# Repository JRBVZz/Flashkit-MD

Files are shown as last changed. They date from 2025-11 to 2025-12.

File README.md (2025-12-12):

#### Flashkit MD дампер картриджей для Sega Mega Drive

Данный дампер/программатор позволяет читать и перезаписывать [совместимые картриджи](https://github.com/JRBVZz/SEGA-MD-Cart). Главное отличие данного форка - это возможность использовать адаптеры для флэш памяти в корпусах TSOP48, таким образом можно выпаять память из несовместимого картриджа и перезаписать её. При этом swap byte для записываемого ROM делать не нужно!

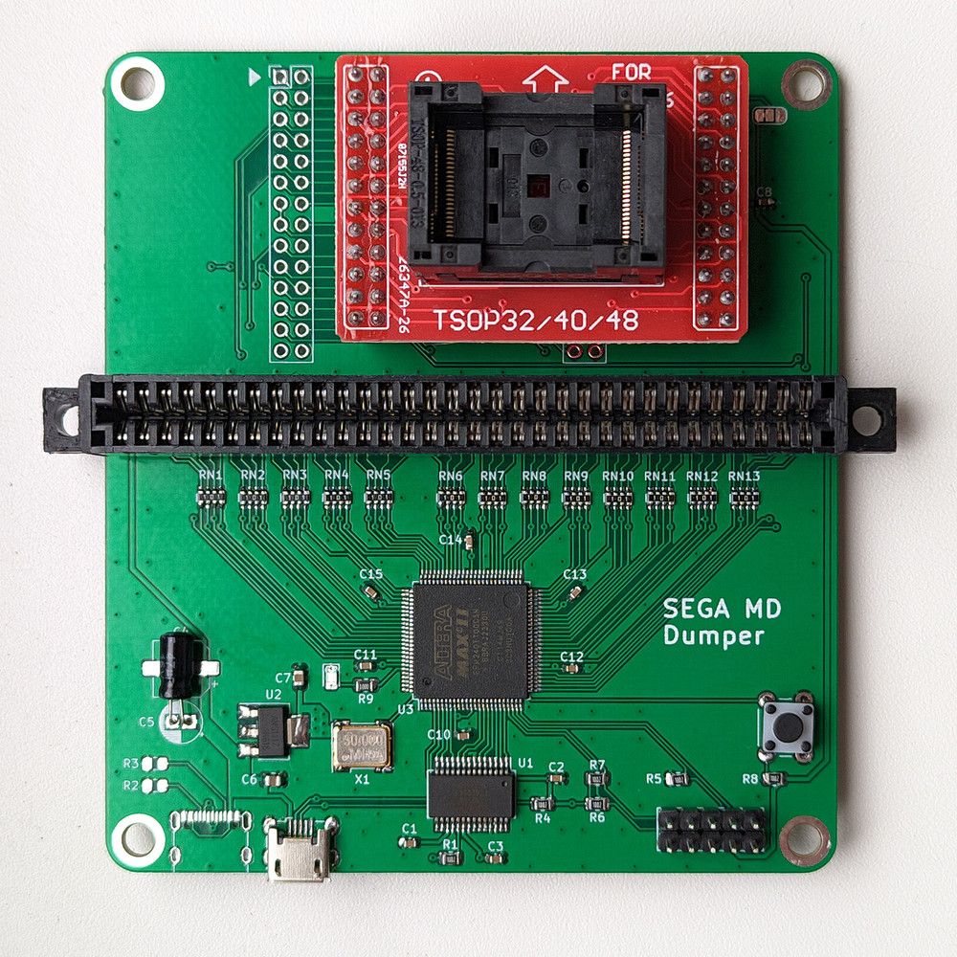
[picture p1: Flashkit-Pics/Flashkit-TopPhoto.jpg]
Front


**Схема**  
[Schematic PDF](Flashkit-Pics/Flashkit-Schematic.pdf)

**Интерактивный BOM**  
[BoM](BOM/Flashkit-iBOM.html) (для корректного просмотра нужно скачать raw файл)

**Прошивка**  
В папке Flashkit-Firmware находятся исходники проекта для Quartus, логика не менялась, был изменен порядок выводов EPM240.

**Софт**  
В папке Flashkit-Soft находится программа для работы с Flashkit и её исходники. Продвинутую версию программы от MiGeRA можно [скачать здесь](https://github.com/MiGeRA/FlashKit-MD-Plus).

**Использование адаптеров**  
В продаже можно найти дешевые TSOP56 адаптеры под пайку (A) и TSOP48 адаптер для TL866 (B), нужна только верхняя часть с кроваткой для микросхемы. Учтите, что у дампера для разных адаптеров свое посадочное место. Для того, чтобы программа увидела адаптер с установленной памятью, необходимо соединить перемычку "FLASH" на плате дампера.

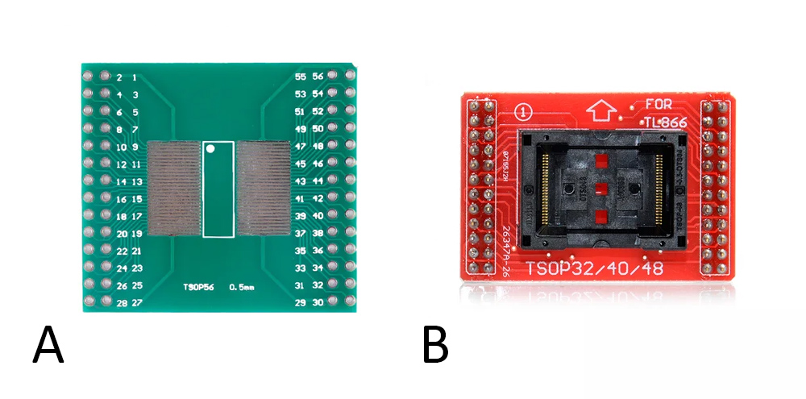
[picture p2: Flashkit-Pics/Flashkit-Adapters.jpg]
Adapters


При запайке чипа памяти в адаптер TSOP56, выводы микросхемы должны располагаться посередине посадочной площадки, т.е. сверху и снизу должно быть свободно по 2 контактные площадки.

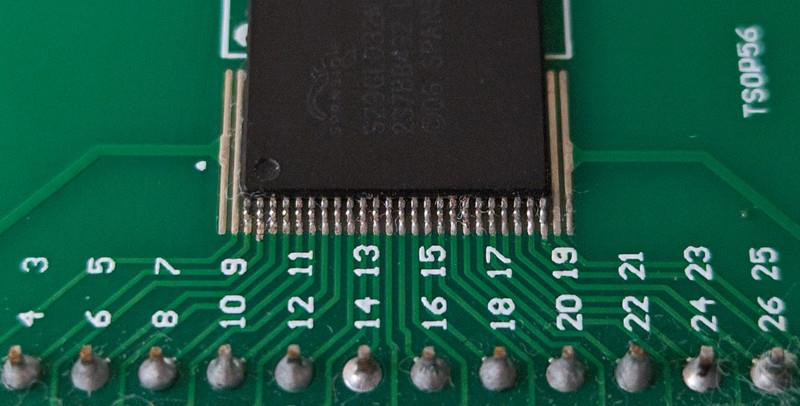
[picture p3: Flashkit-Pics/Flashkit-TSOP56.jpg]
TSOP56

  
Спасибо [**Krikzz**](https://github.com/krikzz) за этот отличный дампер.  
Проект создан в [**KiCad 9**](https://www.kicad.org/).  
PS Герберы не выкладываю специально - это мой небольшой вклад в популяризацию KiCad :smile:

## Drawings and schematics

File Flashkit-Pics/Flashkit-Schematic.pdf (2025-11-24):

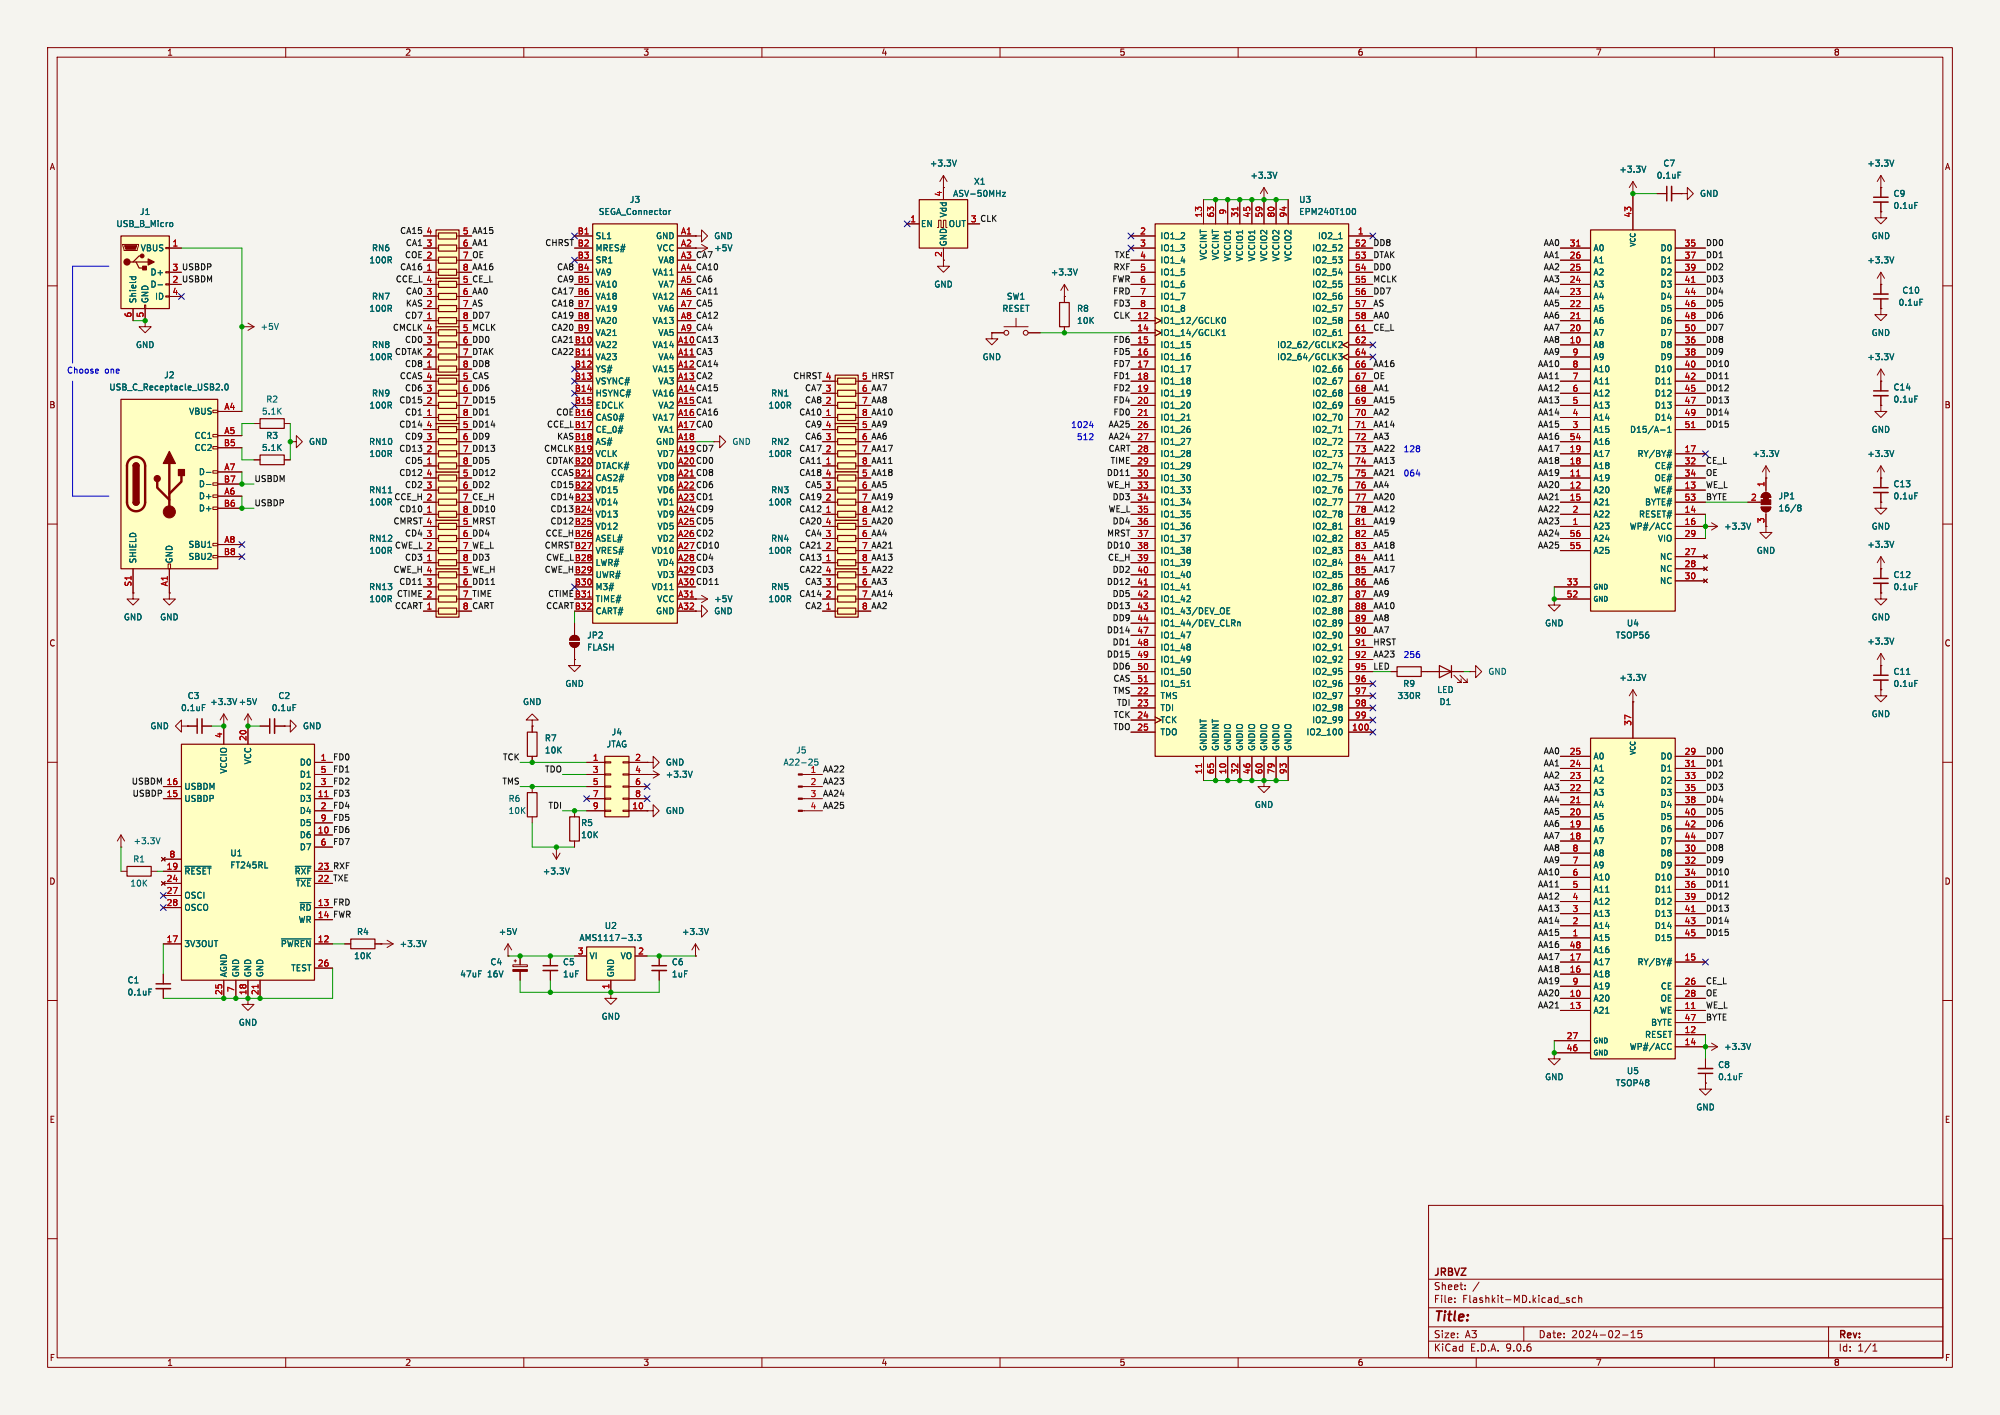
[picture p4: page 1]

J3 SEGA_Connector SL1 B1 MRES# B2 SR1 B3 VA9 B4 VA10 B5 VA18 B6 VA19 B7 VA20 B8 VA21 B9 VA22 B10 VA23 B11 YS# B12 VSYNC# B13 HSYNC# B14 EDCLK B15 CAS0# B16 CE_0# B17 AS# B18 VCLK B19 DTACK# B20 CAS2# B21 VD15 B22 VD14 B23 VD13 B24 VD12 B25 ASEL# B26 VRES# B27
SL1 B1 MRES# B2 SR1 B3 VA9 B4 VA10 B5 VA18 B6 VA19 B7 VA20 B8 VA21 B9 VA22 B10 VA23 B11 YS# B12 VSYNC# B13 HSYNC# B14 EDCLK B15 CAS0# B16 CE_0# B17 AS# B18 VCLK B19 DTACK# B20 CAS2# B21 VD15 B22 VD14 B23 VD13 B24 VD12 B25 ASEL# B26 VRES# B27

9 GNDIO 10 VCCIO1 31 GNDIO 32 VCCIO1 45 GNDIO 46 VCCIO2 59 GNDIO 60 VCCIO2 80 GNDIO 79 VCCIO2 94 GNDIO 93

7 VCC 20 GND 18 GND 21 D0 1 D1 5 D2 3 D3 11 D4 2 D5 9 D6 10 D7 6 ~{RXF}23 ~{TXE}22 ~{RD}13 WR 14 ~{PWREN}12 TEST 26 C1

7 VCC 20 GND 18 GND 21 D0 1 D1 5 D2 3 D3 11 D4 2 D5 9 D6 10 D7 6 ~{RXF}23 ~{TXE}22 ~{RD}13 WR 14 ~{PWREN}12 TEST 26 U1 FT245RL +3.3V GND

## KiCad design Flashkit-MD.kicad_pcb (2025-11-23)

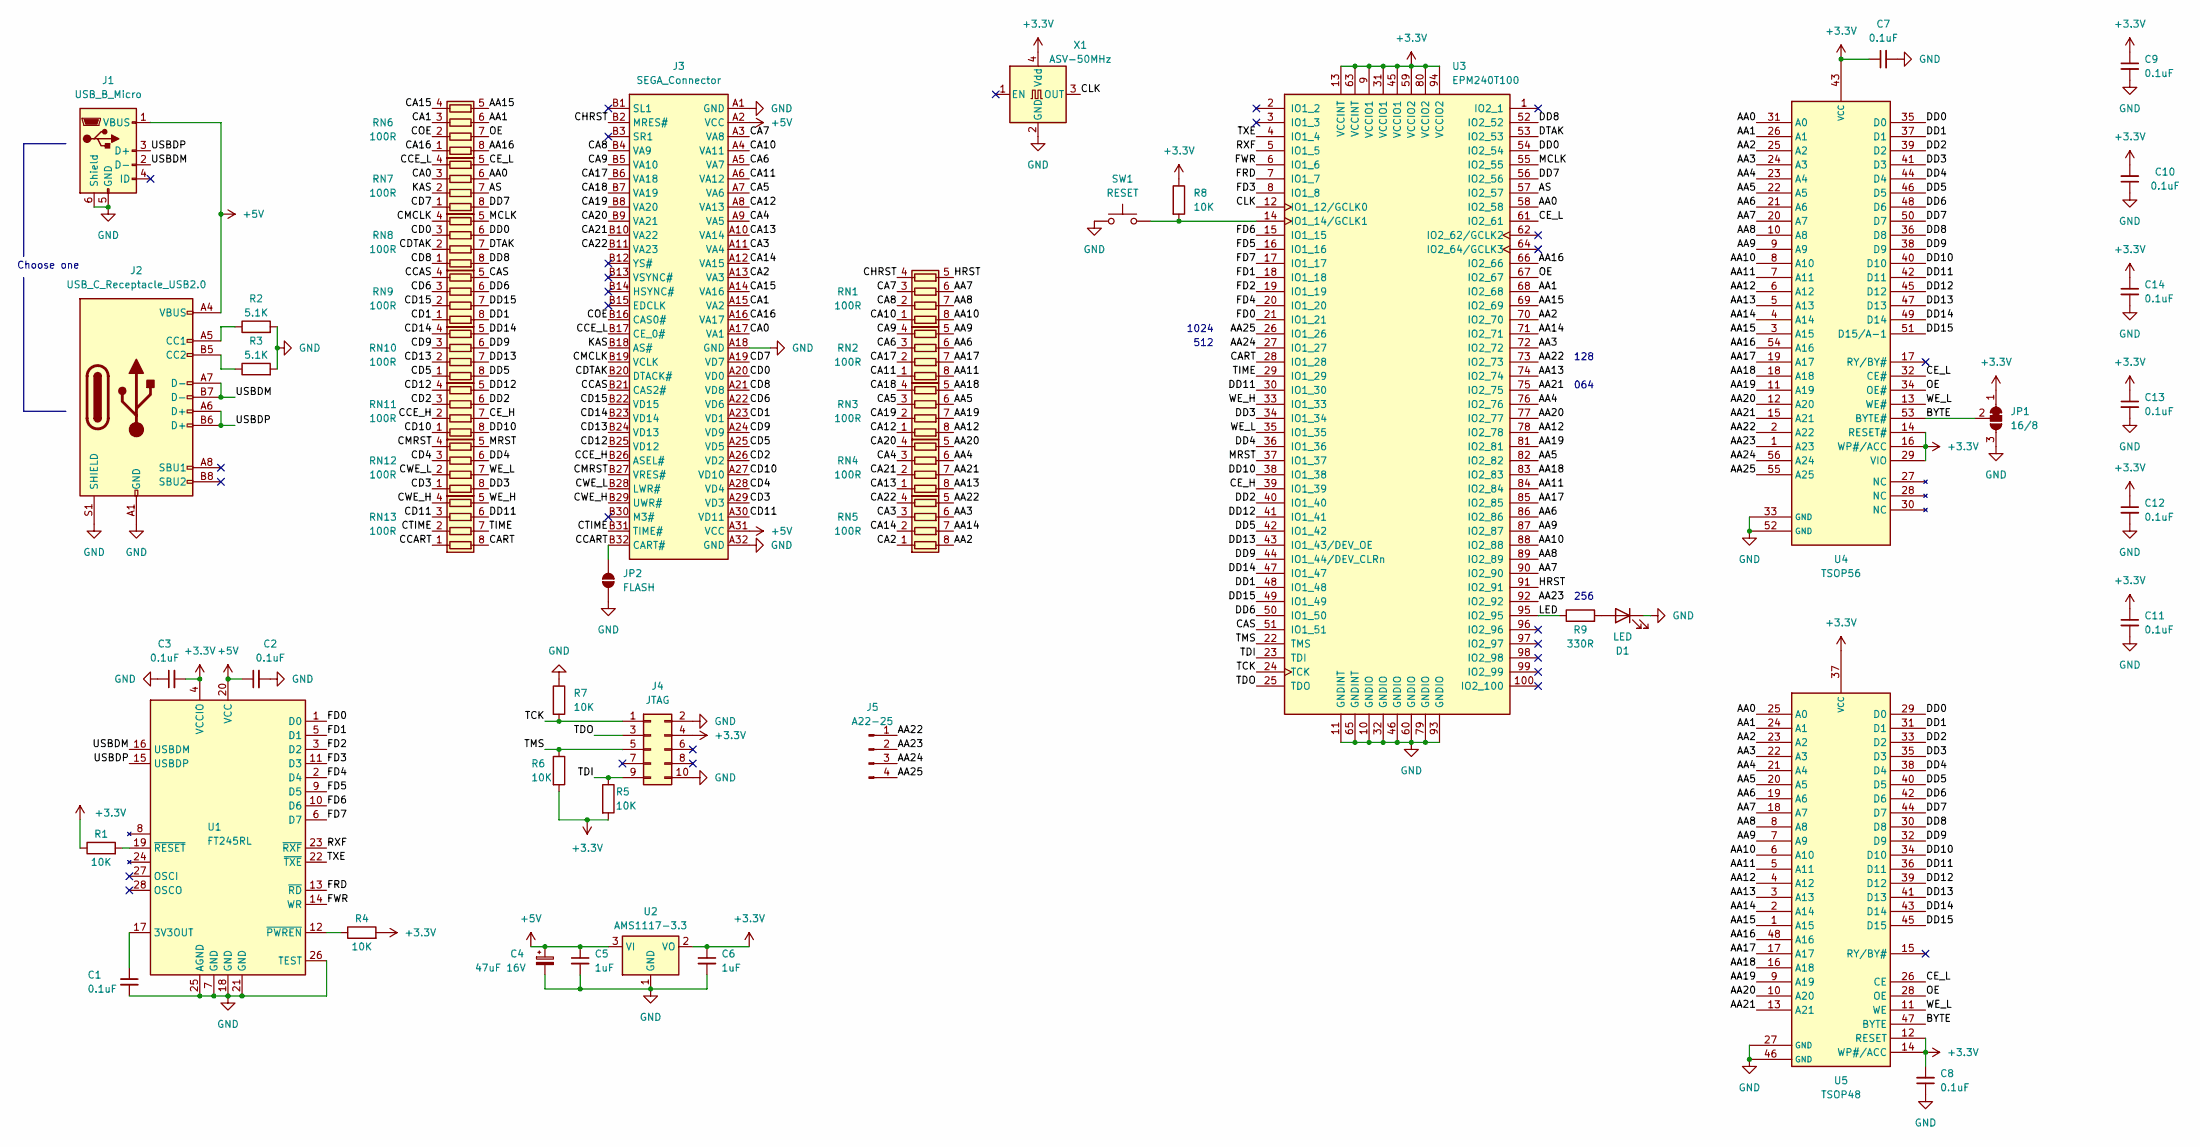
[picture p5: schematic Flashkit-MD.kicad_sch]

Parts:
C1, C2, C3, C7, C8, C9, C10, C11, C12, C13, C14: 0.1uF; C_0603_1608Metric
C4: 47uF 16V; CP_Radial_D5.0mm_P2.00mm
C5, C6: 1uF; C_0805_2012Metric
D1: LED; LED_0805_2012Metric
J1: USB_B_Micro; USB_Micro-B_Wuerth_629105150521
J2: USB_C_Receptacle_USB2.0; USB_C_Receptacle_Palconn_UTC16-G
J3: SEGA_Connector; SEGA_Slot
J4: JTAG; PinHeader_2x05_P2.54mm_Vertical
J5: A22-25; PinHeader_1x04_P2.54mm_Vertical
JP1: 16/8; SolderJumper-3_P1.3mm_Bridged12_RoundedPad1.0x1.5mm
JP2: FLASH; SolderJumper-2_P1.3mm_Open_RoundedPad1.0x1.5mm
R1, R4, R5, R6, R7, R8: 10K; R_0805_2012Metric
R2, R3: 5.1K; R_0805_2012Metric
R9: 330R; R_0805_2012Metric
RN1, RN2, RN3, RN4, RN5, RN6, RN7, RN8, RN9, RN10, RN11, RN12, RN13: 100R; R_Array_Convex_4x0603
SW1: RESET; SW_PUSH_6mm
U1: FT245RL; SSOP-28_5.3x10.2mm_P0.65mm
U2: AMS1117-3.3; SOT-223-3_TabPin2
U3: EPM240T100; LQFP-100_14x14mm_P0.5mm
U4: TSOP56; TSOP56-DIP_P2.54mm
U5: TSOP48; TSOP48_DIP_P2.54mm
X1: ASV-50MHz; Oscillator_SMD_Abracon_ASV-4Pin_7.0x5.1mm

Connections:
+3.3V: C3.2, C6.1, C7.1, C8.2, C9.1, C10.2, C11.1, C12.1, C13.1, C14.1, J4.4, JP1.1 (A), R1.1, R4.2, R5.2, R6.2, R8.1, U1.4 (VCCIO), U2.2 (VO), U3.9 (VCCIO1), U3.13 (VCCINT), U3.31 (VCCIO1), U3.45 (VCCIO1), U3.59 (VCCIO2), U3.63 (VCCINT), U3.80 (VCCIO2), U3.94 (VCCIO2), U4.14 (RESET#), U4.16 (WP#/ACC), U4.29 (VIO), U4.43 (VCC), U5.12 (RESET), U5.14 (WP#/ACC), U5.37 (VCC), X1.4 (Vdd)
+5V: C2.1, C4.1, C5.1, J1.1 (VBUS), J2.A4 (VBUS), J2.A9 (VBUS), J2.B4 (VBUS), J2.B9 (VBUS), J3.A2 (VCC), J3.A31 (VCC), U1.20 (VCC), U2.3 (VI)
/AA0: RN7.6 (R3.2), U3.58 (IO2_58), U4.31 (A0), U5.25 (A0)
/AA1: RN6.6 (R3.2), U3.68 (IO2_68), U4.26 (A1), U5.24 (A1)
/AA2: RN5.8 (R1.2), U3.70 (IO2_70), U4.25 (A2), U5.23 (A2)
/AA3: RN5.6 (R3.2), U3.72 (IO2_72), U4.24 (A3), U5.22 (A3)
/AA4: RN4.6 (R3.2), U3.76 (IO2_76), U4.23 (A4), U5.21 (A4)
/AA5: RN3.6 (R3.2), U3.82 (IO2_82), U4.22 (A5), U5.20 (A5)
/AA6: RN2.6 (R3.2), U3.86 (IO2_86), U4.21 (A6), U5.19 (A6)
/AA7: RN1.6 (R3.2), U3.90 (IO2_90), U4.20 (A7), U5.18 (A7)
/AA8: RN1.7 (R2.2), U3.89 (IO2_89), U4.10 (A8), U5.8 (A8)
/AA9: RN2.5 (R4.2), U3.87 (IO2_87), U4.9 (A9), U5.7 (A9)
/AA10: RN1.8 (R1.2), U3.88 (IO2_88), U4.8 (A10), U5.6 (A10)
/AA11: RN2.8 (R1.2), U3.84 (IO2_84), U4.7 (A11), U5.5 (A11)
/AA12: RN3.8 (R1.2), U3.78 (IO2_78), U4.6 (A12), U5.4 (A12)
/AA13: RN4.8 (R1.2), U3.74 (IO2_74), U4.5 (A13), U5.3 (A13)
/AA14: RN5.7 (R2.2), U3.71 (IO2_71), U4.4 (A14), U5.2 (A14)
/AA15: RN6.5 (R4.2), U3.69 (IO2_69), U4.3 (A15), U5.1 (A15)
/AA16: RN6.8 (R1.2), U3.66 (IO2_66), U4.54 (A16), U5.48 (A16)
/AA17: RN2.7 (R2.2), U3.85 (IO2_85), U4.19 (A17), U5.17 (A17)
/AA18: RN3.5 (R4.2), U3.83 (IO2_83), U4.18 (A18), U5.16 (A18)
/AA19: RN3.7 (R2.2), U3.81 (IO2_81), U4.11 (A19), U5.9 (A19)
/AA20: RN4.5 (R4.2), U3.77 (IO2_77), U4.12 (A20), U5.10 (A20)
/AA21: RN4.7 (R2.2), U3.75 (IO2_75), U4.15 (A21), U5.13 (A21)
/AA22: J5.1, RN5.5 (R4.2), U3.73 (IO2_73), U4.2 (A22)
/AA23: J5.2, U3.92 (IO2_92), U4.1 (A23)
/AA24: J5.3, U3.27 (IO1_27), U4.56 (A24)
/AA25: J5.4, U3.26 (IO1_26), U4.55 (A25)
/AS: RN7.7 (R2.2), U3.57 (IO2_57)
/BYTE: JP1.2 (C), U4.53 (BYTE#), U5.47 (BYTE)
/CA0: J3.A17 (VA1), RN7.3 (R3.1)
/CA1: J3.A15 (VA2), RN6.3 (R3.1)
/CA2: J3.A13 (VA3), RN5.1 (R1.1)
/CA3: J3.A11 (VA4), RN5.3 (R3.1)
/CA4: J3.A9 (VA5), RN4.3 (R3.1)
/CA5: J3.A7 (VA6), RN3.3 (R3.1)
/CA6: J3.A5 (VA7), RN2.3 (R3.1)
/CA7: J3.A3 (VA8), RN1.3 (R3.1)
/CA8: J3.B4 (VA9), RN1.2 (R2.1)
/CA9: J3.B5 (VA10), RN2.4 (R4.1)
/CA10: J3.A4 (VA11), RN1.1 (R1.1)
/CA11: J3.A6 (VA12), RN2.1 (R1.1)
/CA12: J3.A8 (VA13), RN3.1 (R1.1)
/CA13: J3.A10 (VA14), RN4.1 (R1.1)
/CA14: J3.A12 (VA15), RN5.2 (R2.1)
/CA15: J3.A14 (VA16), RN6.4 (R4.1)
/CA16: J3.A16 (VA17), RN6.1 (R1.1)
/CA17: J3.B6 (VA18), RN2.2 (R2.1)
/CA18: J3.B7 (VA19), RN3.4 (R4.1)
/CA19: J3.B8 (VA20), RN3.2 (R2.1)
/CA20: J3.B9 (VA21), RN4.4 (R4.1)
/CA21: J3.B10 (VA22), RN4.2 (R2.1)
/CA22: J3.B11 (VA23), RN5.4 (R4.1)
/CART: RN13.8 (R1.2), U3.28 (IO1_28)
/CAS: RN9.5 (R4.2), U3.51 (IO1_51)
/CCART: J3.B32 (CART#), JP2.2 (B), RN13.1 (R1.1)
/CCAS: J3.B21 (CAS2#), RN9.4 (R4.1)
/CCE_H: J3.B26 (ASEL#), RN11.2 (R2.1)
/CCE_L: J3.B17 (CE_0#), RN7.4 (R4.1)
/CD0: J3.A20 (VD0), RN8.3 (R3.1)
/CD1: J3.A23 (VD1), RN9.1 (R1.1)
/CD2: J3.A26 (VD2), RN11.3 (R3.1)
/CD3: J3.A29 (VD3), RN12.1 (R1.1)
/CD4: J3.A28 (VD4), RN12.3 (R3.1)
/CD5: J3.A25 (VD5), RN10.1 (R1.1)
/CD6: J3.A22 (VD6), RN9.3 (R3.1)
/CD7: J3.A19 (VD7), RN7.1 (R1.1)
/CD8: J3.A21 (VD8), RN8.1 (R1.1)
/CD9: J3.A24 (VD9), RN10.3 (R3.1)
/CD10: J3.A27 (VD10), RN11.1 (R1.1)
/CD11: J3.A30 (VD11), RN13.3 (R3.1)
/CD12: J3.B25 (VD12), RN11.4 (R4.1)
/CD13: J3.B24 (VD13), RN10.2 (R2.1)
/CD14: J3.B23 (VD14), RN10.4 (R4.1)
/CD15: J3.B22 (VD15), RN9.2 (R2.1)
/CDTAK: J3.B20 (DTACK#), RN8.2 (R2.1)
/CE_H: RN11.7 (R2.2), U3.39 (IO1_39)
/CE_L: RN7.5 (R4.2), U3.61 (IO2_61), U4.32 (CE#), U5.26 (CE)
/CHRST: J3.B2 (MRES#), RN1.4 (R4.1)
/CLK: U3.12 (IO1_12/GCLK0), X1.3 (OUT)
/CMCLK: J3.B19 (VCLK), RN8.4 (R4.1)
/CMRST: J3.B27 (VRES#), RN12.4 (R4.1)
/COE: J3.B16 (CAS0#), RN6.2 (R2.1)
/CTIME: J3.B31 (TIME#), RN13.2 (R2.1)
/CWE_H: J3.B29 (UWR#), RN13.4 (R4.1)
/CWE_L: J3.B28 (LWR#), RN12.2 (R2.1)
/DD0: RN8.6 (R3.2), U3.54 (IO2_54), U4.35 (D0), U5.29 (D0)
/DD1: RN9.8 (R1.2), U3.48 (IO1_48), U4.37 (D1), U5.31 (D1)
/DD2: RN11.6 (R3.2), U3.40 (IO1_40), U4.39 (D2), U5.33 (D2)
/DD3: RN12.8 (R1.2), U3.34 (IO1_34), U4.41 (D3), U5.35 (D3)
/DD4: RN12.6 (R3.2), U3.36 (IO1_36), U4.44 (D4), U5.38 (D4)
/DD5: RN10.8 (R1.2), U3.42 (IO1_42), U4.46 (D5), U5.40 (D5)
/DD6: RN9.6 (R3.2), U3.50 (IO1_50), U4.48 (D6), U5.42 (D6)
/DD7: RN7.8 (R1.2), U3.56 (IO2_56), U4.50 (D7), U5.44 (D7)
/DD8: RN8.8 (R1.2), U3.52 (IO2_52), U4.36 (D8), U5.30 (D8)
/DD9: RN10.6 (R3.2), U3.44 (IO1_44/DEV_CLRn), U4.38 (D9), U5.32 (D9)
/DD10: RN11.8 (R1.2), U3.38 (IO1_38), U4.40 (D10), U5.34 (D10)
/DD11: RN13.6 (R3.2), U3.30 (IO1_30), U4.42 (D11), U5.36 (D11)
/DD12: RN11.5 (R4.2), U3.41 (IO1_41), U4.45 (D12), U5.39 (D12)
/DD13: RN10.7 (R2.2), U3.43 (IO1_43/DEV_OE), U4.47 (D13), U5.41 (D13)
/DD14: RN10.5 (R4.2), U3.47 (IO1_47), U4.49 (D14), U5.43 (D14)
/DD15: RN9.7 (R2.2), U3.49 (IO1_49), U4.51 (D15/A-1), U5.45 (D15)
/DTAK: RN8.7 (R2.2), U3.53 (IO2_53)
/FD0: U1.1 (D0), U3.21 (IO1_21)
/FD1: U1.5 (D1), U3.18 (IO1_18)
/FD2: U1.3 (D2), U3.19 (IO1_19)
/FD3: U1.11 (D3), U3.8 (IO1_8)
/FD4: U1.2 (D4), U3.20 (IO1_20)
/FD5: U1.9 (D5), U3.16 (IO1_16)
/FD6: U1.10 (D6), U3.15 (IO1_15)
/FD7: U1.6 (D7), U3.17 (IO1_17)
/FRD: U1.13 (~RD), U3.7 (IO1_7)
/FWR: U1.14 (WR), U3.6 (IO1_6)
/HRST: RN1.5 (R4.2), U3.91 (IO2_91)
/KAS: J3.B18 (AS#), RN7.2 (R2.1)
/LED: R9.1, U3.95 (IO2_95)
/MCLK: RN8.5 (R4.2), U3.55 (IO2_55)
/MRST: RN12.5 (R4.2), U3.37 (IO1_37)
/OE: RN6.7 (R2.2), U3.67 (IO2_67), U4.34 (OE#), U5.28 (OE)
/RXF: U1.23 (~RXF), U3.5 (IO1_5)
/TCK: J4.1, R7.2, U3.24 (TCK)
/TDI: J4.9, R5.1, U3.23 (TDI)
/TDO: J4.3, U3.25 (TDO)
/TIME: RN13.7 (R2.2), U3.29 (IO1_29)
/TMS: J4.5, R6.1, U3.22 (TMS)
/TXE: U1.22 (~TXE), U3.4 (IO1_4)
/USBDM: J1.2 (D-), J2.A7 (D-), J2.B7 (D-), U1.16 (USBDM)
/USBDP: J1.3 (D+), J2.A6 (D+), J2.B6 (D+), U1.15 (USBDP)
/WE_H: RN13.5 (R4.2), U3.33 (IO1_33)
/WE_L: RN12.7 (R2.2), U3.35 (IO1_35), U4.13 (WE#), U5.11 (WE)
GND: C1.2, C2.2, C3.1, C4.2, C5.2, C6.2, C7.2, C8.1, C9.2, C10.1, C11.2, C12.2, C13.2, C14.2, D1.1 (K), J1.5 (GND), J1.6 (Shield), J2.A1 (GND), J2.A12 (GND), J2.B1 (GND), J2.B12 (GND), J2.S1 (SHIELD), J3.A1 (GND), J3.A18 (GND), J3.A32 (GND), J4.2, J4.10, JP1.3 (B), JP2.1 (A), R2.2, R3.2, R7.1, SW1.1, U1.7 (GND), U1.18 (GND), U1.21 (GND), U1.25 (AGND), U1.26 (TEST), U2.1 (GND), U3.10 (GNDIO), U3.11 (GNDINT), U3.32 (GNDIO), U3.46 (GNDIO), U3.60 (GNDIO), U3.65 (GNDINT), U3.79 (GNDIO), U3.93 (GNDIO), U4.33 (GND), U4.52 (GND), U5.27 (GND), U5.46 (GND), X1.2 (GND)
unnamed: D1.2 (A), R9.2
unnamed: J2.A5 (CC1), R2.1
unnamed: J2.B5 (CC2), R3.1
unnamed: C1.1, U1.17 (3V3OUT)
unnamed: R4.1, U1.12 (~PWREN)
unnamed: R1.2, U1.19 (~RESET)
unnamed: R8.2, SW1.2, U3.14 (IO1_14/GCLK1)

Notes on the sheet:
512
1024
128
064
256
Choose one

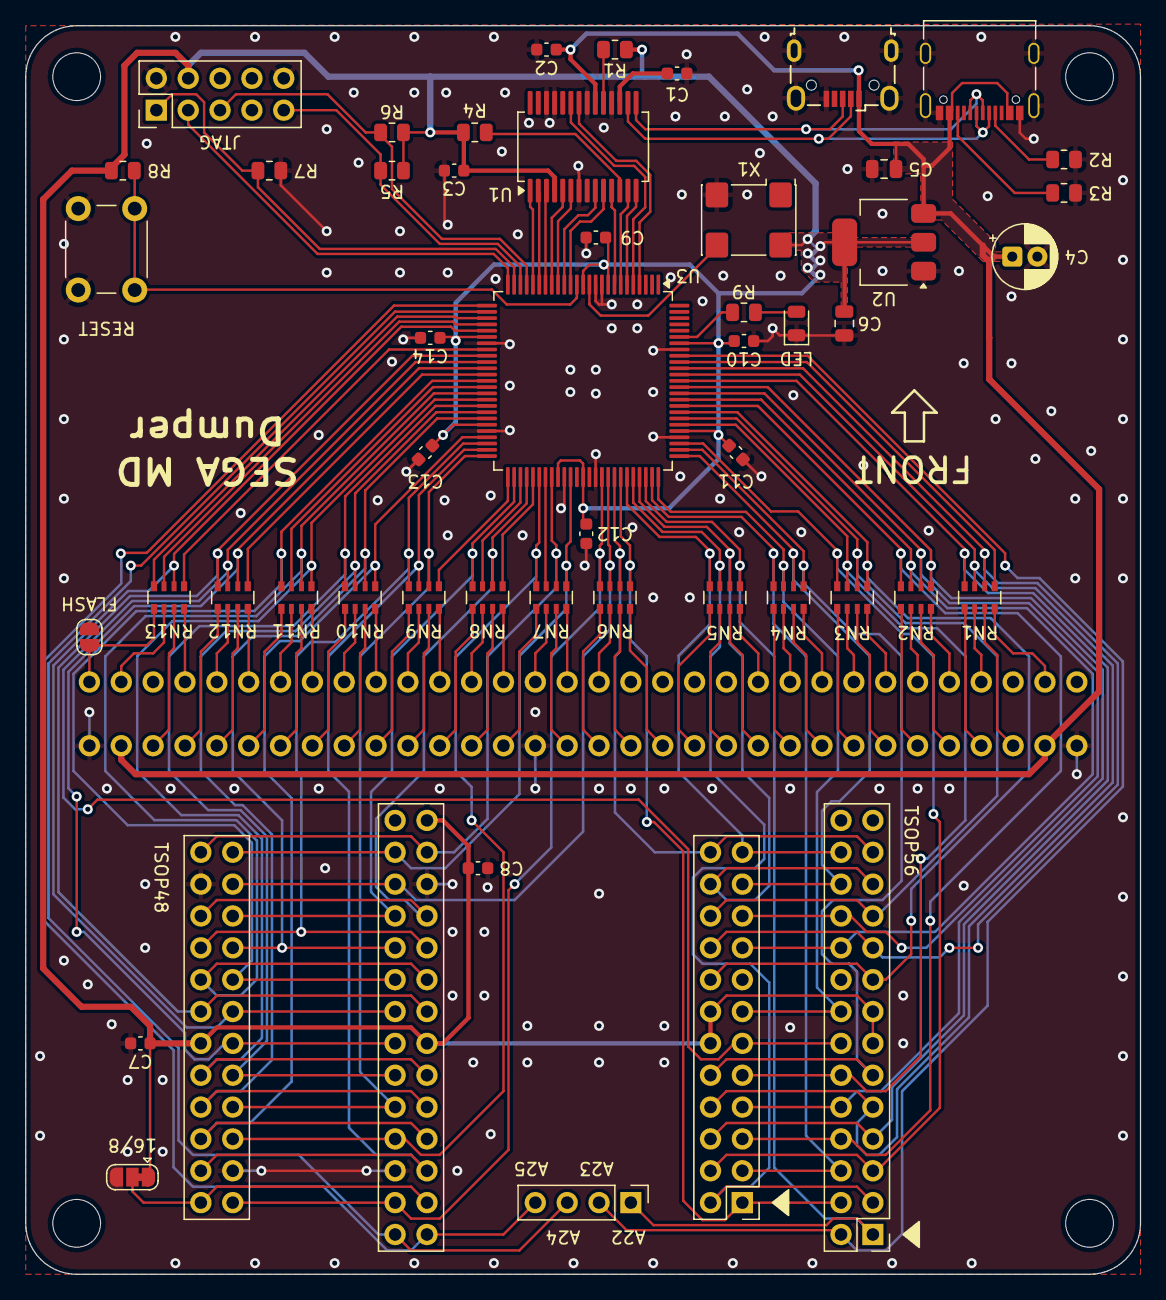
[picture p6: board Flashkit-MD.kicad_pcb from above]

Board: 2 copper layers, 88.9 x 99.6 mm, 51 parts (0 on the bottom side), 138 nets.

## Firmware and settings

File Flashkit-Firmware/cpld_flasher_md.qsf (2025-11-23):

# -------------------------------------------------------------------------- #
#
# Copyright (C) 1991-2013 Altera Corporation
# Your use of Altera Corporation's design tools, logic functions 
# and other software and tools, and its AMPP partner logic 
# functions, and any output files from any of the foregoing 
# (including device programming or simulation files), and any 
# associated documentation or information are expressly subject 
# to the terms and conditions of the Altera Program License 
# Subscription Agreement, Altera MegaCore Function License 
# Agreement, or other applicable license agreement, including, 
# without limitation, that your use is for the sole purpose of 
# programming logic devices manufactured by Altera and sold by 
# Altera or its authorized distributors.  Please refer to the 
# applicable agreement for further details.
#
# -------------------------------------------------------------------------- #
#
# Quartus II 64-Bit
# Version 13.0.1 Build 232 06/12/2013 Service Pack 1 SJ Web Edition
# Date created = 08:10:07  December 13, 2013
#
# -------------------------------------------------------------------------- #
#
# Notes:
#
# 1) The default values for assignments are stored in the file:
#		cpld_flasher_md_assignment_defaults.qdf
#    If this file doesn't exist, see file:
#		assignment_defaults.qdf
#
# 2) Altera recommends that you do not modify this file. This
#    file is updated automatically by the Quartus II software
#    and any changes you make may be lost or overwritten.
#
# -------------------------------------------------------------------------- #


set_global_assignment -name FAMILY "MAX II"
set_global_assignment -name DEVICE EPM240T100C5
set_global_assignment -name TOP_LEVEL_ENTITY flasher_md
set_global_assignment -name ORIGINAL_QUARTUS_VERSION "13.0 SP1"
set_global_assignment -name PROJECT_CREATION_TIME_DATE "08:10:07  DECEMBER 13, 2013"
set_global_assignment -name LAST_QUARTUS_VERSION "18.0.0 Standard Edition"
set_global_assignment -name PROJECT_OUTPUT_DIRECTORY output_files
set_global_assignment -name MIN_CORE_JUNCTION_TEMP 0
set_global_assignment -name MAX_CORE_JUNCTION_TEMP 85
set_global_assignment -name DEVICE_FILTER_PACKAGE "ANY QFP"
set_global_assignment -name DEVICE_FILTER_PIN_COUNT 100
set_global_assignment -name ERROR_CHECK_FREQUENCY_DIVISOR "-1"
set_global_assignment -name POWER_EXT_SUPPLY_VOLTAGE_TO_REGULATOR 3.3V
set_global_assignment -name VERILOG_FILE flasher_md.v
set_global_assignment -name STRATIX_DEVICE_IO_STANDARD "3.3-V LVTTL"
set_location_assignment PIN_58 -to addr[0]
set_location_assignment PIN_68 -to addr[1]
set_location_assignment PIN_70 -to addr[2]
set_location_assignment PIN_72 -to addr[3]
set_location_assignment PIN_76 -to addr[4]
set_location_assignment PIN_82 -to addr[5]
set_location_assignment PIN_86 -to addr[6]
set_location_assignment PIN_90 -to addr[7]
set_location_assignment PIN_89 -to addr[8]
set_location_assignment PIN_87 -to addr[9]
set_location_assignment PIN_88 -to addr[10]
set_location_assignment PIN_84 -to addr[11]
set_location_assignment PIN_78 -to addr[12]
set_location_assignment PIN_74 -to addr[13]
set_location_assignment PIN_71 -to addr[14]
set_location_assignment PIN_69 -to addr[15]
set_location_assignment PIN_66 -to addr[16]
set_location_assignment PIN_85 -to addr[17]
set_location_assignment PIN_83 -to addr[18]
set_location_assignment PIN_81 -to addr[19]
set_location_assignment PIN_77 -to addr[20]
set_location_assignment PIN_75 -to addr[21]
set_location_assignment PIN_73 -to addr[22]
set_location_assignment PIN_57 -to as
set_location_assignment PIN_28 -to cart
set_location_assignment PIN_51 -to cas
set_location_assignment PIN_39 -to ce_hi
set_location_assignment PIN_61 -to ce_lo
set_location_assignment PIN_12 -to clk
set_location_assignment PIN_54 -to dat[0]
set_location_assignment PIN_48 -to dat[1]
set_location_assignment PIN_40 -to dat[2]
set_location_assignment PIN_34 -to dat[3]
set_location_assignment PIN_36 -to dat[4]
set_location_assignment PIN_42 -to dat[5]
set_location_assignment PIN_50 -to dat[6]
set_location_assignment PIN_56 -to dat[7]
set_location_assignment PIN_52 -to dat[8]
set_location_assignment PIN_44 -to dat[9]
set_location_assignment PIN_38 -to dat[10]
set_location_assignment PIN_30 -to dat[11]
set_location_assignment PIN_41 -to dat[12]
set_location_assignment PIN_43 -to dat[13]
set_location_assignment PIN_47 -to dat[14]
set_location_assignment PIN_49 -to dat[15]
set_location_assignment PIN_53 -to dtak
set_location_assignment PIN_21 -to fdat[0]
set_location_assignment PIN_18 -to fdat[1]
set_location_assignment PIN_19 -to fdat[2]
set_location_assignment PIN_8 -to fdat[3]
set_location_assignment PIN_20 -to fdat[4]
set_location_assignment PIN_16 -to fdat[5]
set_location_assignment PIN_15 -to fdat[6]
set_location_assignment PIN_17 -to fdat[7]
set_location_assignment PIN_7 -to frd
set_location_assignment PIN_6 -to fwr
set_location_assignment PIN_91 -to hrst
set_location_assignment PIN_95 -to led
set_location_assignment PIN_55 -to mclk
set_location_assignment PIN_37 -to mrst
set_location_assignment PIN_67 -to oe
set_location_assignment PIN_14 -to rst
set_location_assignment PIN_5 -to rxf
set_location_assignment PIN_29 -to tim
set_location_assignment PIN_4 -to txe
set_location_assignment PIN_33 -to we_hi
set_location_assignment PIN_35 -to we_lo
set_instance_assignment -name WEAK_PULL_UP_RESISTOR ON -to dat[15]
set_instance_assignment -name WEAK_PULL_UP_RESISTOR ON -to dat[14]
set_instance_assignment -name WEAK_PULL_UP_RESISTOR ON -to dat[13]
set_instance_assignment -name WEAK_PULL_UP_RESISTOR ON -to dat[12]
set_instance_assignment -name WEAK_PULL_UP_RESISTOR ON -to dat[11]
set_instance_assignment -name WEAK_PULL_UP_RESISTOR ON -to dat[10]
set_instance_assignment -name WEAK_PULL_UP_RESISTOR ON -to dat[9]
set_instance_assignment -name WEAK_PULL_UP_RESISTOR ON -to dat[8]
set_instance_assignment -name WEAK_PULL_UP_RESISTOR ON -to dat[7]
set_instance_assignment -name WEAK_PULL_UP_RESISTOR ON -to dat[6]
set_instance_assignment -name WEAK_PULL_UP_RESISTOR ON -to dat[5]
set_instance_assignment -name WEAK_PULL_UP_RESISTOR ON -to dat[4]
set_instance_assignment -name WEAK_PULL_UP_RESISTOR ON -to dat[3]
set_instance_assignment -name WEAK_PULL_UP_RESISTOR ON -to dat[2]
set_instance_assignment -name WEAK_PULL_UP_RESISTOR ON -to dat[1]
set_instance_assignment -name WEAK_PULL_UP_RESISTOR ON -to dat[0]
set_instance_assignment -name WEAK_PULL_UP_RESISTOR ON -to dtak
set_instance_assignment -name WEAK_PULL_UP_RESISTOR ON -to mrst
set_instance_assignment -name WEAK_PULL_UP_RESISTOR ON -to hrst
set_instance_assignment -name WEAK_PULL_UP_RESISTOR ON -to cart
